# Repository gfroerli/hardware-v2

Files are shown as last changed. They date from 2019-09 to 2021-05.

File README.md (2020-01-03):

# Gfrörli Sensor Hardware v2

Based on the STM32L071KB microcontroller and the RN2483 LoRaWAN
modem.

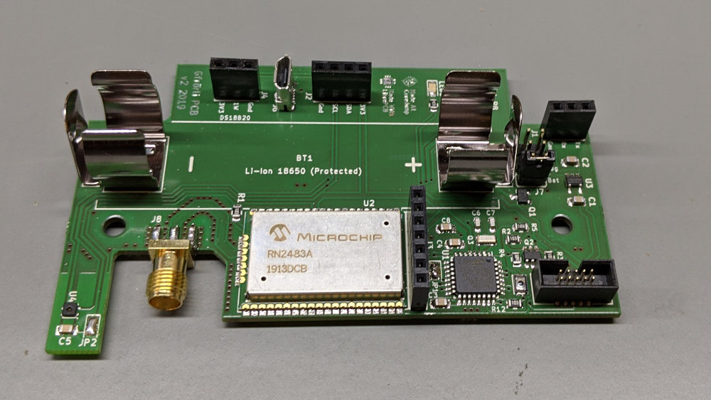
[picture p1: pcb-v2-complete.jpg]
Photo of assembled PCB


Aisler order link for v2.0: https://aisler.net/p/OROZOWMP

This is a [LibrePCB](https://librepcb.org) project!

## Docs

See [`docs/index.md`](./docs/index.md)

## License

No license set.

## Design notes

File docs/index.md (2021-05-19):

# Gfrör.li Documentation

## RN2483

See [`rn2483.md`](./rn2483.md).

## STM32L071

See [`stm32l071.md`](./stm32l071.md)

## Antenna / RF

See [`rf.md`](./rf.md)

## Debugger

We use the Segger JLink debugger.

The adaper used is the
[ARM-JTAG-20-10](https://www.digikey.ch/product-detail/de/olimex-ltd/ARM-JTAG-20-10/1188-1016-ND/3471401)
by OLIMEX.

- [Digikey](https://www.digikey.ch/product-detail/de/olimex-ltd/ARM-JTAG-20-10/1188-1016-ND/3471401)
- [Olimex Store](https://www.olimex.com/Products/ARM/JTAG/ARM-JTAG-20-10/)
- [Schematics](../datasheets/ARM-JTAG-20-10_latest-schematic.pdf)

## Powering the PCB

There are 3 ways to power the PCB:

- Battery power (3.3-4.2V)
- USB (5V)
- Debug probe (5V)

To choose the power source, the jumper J7 needs to be set appropriately.

If you want to power the board through the JLink debug probe, the solder bridge
R1 on the OLIMEX adapter must be closed. Then 5V power will be [supplied on pin
7 of the connector](../datasheets/ARM-JTAG-20-10_latest-schematic.pdf).

### Power Consumption

The peak power consumption is:
 * RN2483: ~40mA
 * STM32L071: ~10mA (IDD is 7.4mA according to datasheet Table 29.)
 * LEDs: ~10mA
 * SHTC3: ~1mA
 * DS18B20: ~1.5mA

So if we calculate with a peak power consumption of 100mA we should be on the safe side.

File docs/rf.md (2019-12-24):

# Antenna / RF

## Trace Calculations

The specs used by Aisler for their standard HASL boards:

- [FR-4-86](https://aisler.net/help/design-rules-and-specifications/specifications/2_layer_datasheet.pdf)
  - Dielectric constant / permittivity @ 1 MHz: Max 5.4 Measured 4.7
  - Loss Tangent @ 1 MHz: Max 0.035 Measured 0.02
- Copper thickness: 35 µm
- Board thickness: 1.6 mm

The current PCB layout uses a coplanar wave guide with ground plane.

With 0.3mm plane clearance:

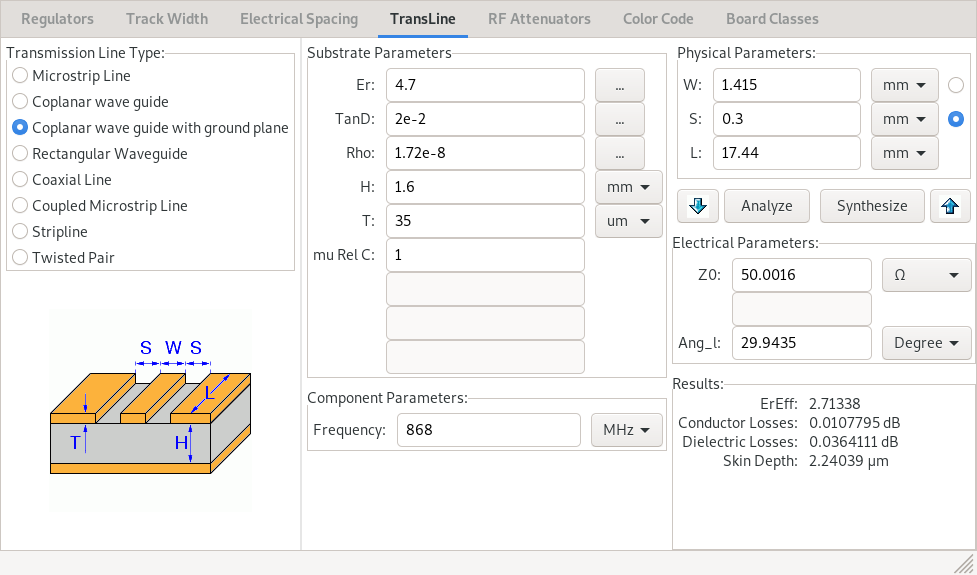
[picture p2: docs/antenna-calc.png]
Antenna coplanar waveguide calculations in KiCAD


With a trace width of 1.415 mm we should get an impedance of 50.0016 Ω.

See https://github.com/gfroerli/hardware-v2/issues/30 for more details.

## SMA Connector

We use a 50 Ω edge mount female SMA connector
[CON-SMA-EDGE-S](https://www.digikey.ch/products/en?keywords=%20CON-SMA-EDGE-S)
by RF Solutions. It seems to have the same footprint as the [Samtec
SMA-J-P-H-ST-EM1](https://www.digikey.com/product-detail/en/samtec-inc/SMA-J-P-H-ST-EM1/SAM8857-ND/2602450).

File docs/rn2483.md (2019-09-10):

# RN2483

## Information

 * https://www.microchip.com/wwwproducts/en/RN2483

## Firmware Update

See chapter 3.6 in the datasheet.

### Regular

The regular firmware upgrade happens through the bootloader via UART.

### Emergency

For the emergency firmware download (device bricked) one needs to connect
PGC\_INT, PGD\_INT NRESET, power and ground.

The NRESET pin will be driven with 9V during the upgrade, so any connected
parts may need protection!

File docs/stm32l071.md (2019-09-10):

# STM32L071

## Clock

See "Low-speed external clock generated from a crystal/ceramic resonator" in
the datasheet.

Our model only has the low-speed external clock pins. So we either use a more
precise external low speed clock or the less precise internal clocks.

## Nucleo Board (NUCLEO-L031K6)

The board we used for evaluation.

[Datasheet](../datasheets/STM32-Nucleo-32-boards.pdf)

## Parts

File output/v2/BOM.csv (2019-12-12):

Quantity | Designators | Value | Device | Package | PARTNUMBER | DIGIKEY | MANUFACTURER
1 | BT1 | 54 | Keystone 54 Battery Clips | KEYSTONE_54 | 54 | 36-54-ND | Keystone
2 | C1, C2 | 1μF | C-0805 | C-0805 | CL21B105KOFNNNG | 1276-6471-1-ND | Samsung
4 | C3, C4, C5, C8 | 100nF | C-0805 | C-0805 | CL21B104KACNNNC | 1276-1099-1-ND | Samsung
2 | C6, C7 | 4.3pF | C-0603 | C-0603 | CC0603CRNPO9BN4R3 | 311-3858-1-ND | Yageo
1 | J1 | UART1_DBG | Generic Pin Socket 2.54mm 1x03 ⌀1.0mm | Pin Socket 2.54mm 1x03 ⌀1.0mm | PPTC031LFBN-RC | S7001-ND | Sullins
1 | J2 | I2C | Generic Pin Socket 2.54mm 1x04 ⌀1.0mm | Pin Socket 2.54mm 1x04 ⌀1.0mm | PPTC041LFBN-RC | S7002-ND | Sullins
1 | J3 | RN | Generic Pin Socket 2.54mm 1x07 ⌀1.0mm | Pin Socket 2.54mm 1x07 ⌀1.0mm | PPTC071LFBN-RC | S7005-ND | Sullins
1 | J4 | DS18B20 | Soldered Wire Connector 2.54mm 1x03 ⌀1.0mm | Soldered Wire Connector 1x03 ⌀1.0mm | DFR0198 | DFR0198 | DFRobot
1 | J5 | SWD Connector 3220-10-0300-00 | CNC Tech 3220-10-0300 | CNCTECH_3220-10-0300-XX | 3220-10-0300-00 | 1175-1629-ND | CNC Tech
1 | J6 | Micro USB (power only) | Molex 1051330001 | MOLEX_1051330001 | 1051330001 | WM9734CT-ND | Molex
1 | J7 | Power Selector Jumper | Generic Pin Header 2.54mm 2x03 ⌀1.0mm | Pin Header 2.54mm 2x03 ⌀1.0mm | PRPC003DAAN-RC | S2011EC-03-ND | Sullins
1 | J7+ | Power Selector Jumper |  |  | QPC02SXGN-RC | S9337-ND | Sullins
1 | J8 | SMA CON-SMA-EDGE-S | RF Solutions CON-SMA-EDGE-S | RFSOL_CON-SMA-EDGE-S | CON-SMA-EDGE-S | CON-SMA-EDGE-S-ND | RF Solutions
1 | LED1 | R 2V 2.8mA | OSRAM LS R976-NR-1 | OSRAM CHIPLED 0805 Diffused | LS R976-NR-1 | 475-1278-1-ND | Osram
1 | LED2 | Y 2V 2.8mA | OSRAM LY R976-PS-36 | OSRAM CHIPLED 0805 Diffused | LY R976-PS-36 | 475-2560-1-ND | Osram
1 | LED3 | G 2.2V 2.3mA | OSRAM LG R971-KN-1 | OSRAM CHIPLED 0805 Diffused | LG R971-KN-1 | 475-1410-1-ND | Osram
1 | Q1 | SSM3J338R,LF | Toshiba SSM3J338R | SOT23-3 | SSM3J338R,LF | SSM3J338RLFCT-ND | Toshiba
1 | Q2 | DMG6601LVT | DMG6601LVT | SOT95P280X145-6 | DMG6601LVT | DMG6601LVT-7DICT-ND | Diodes Incorporated
1 | Q3 | 32,768Hz | NX3215SA Crystal | NDK_NX3215SA | NX3215SA-32.768KHZ-EXS00A-MU00529 | 644-1388-1-ND | NDK
6 | R1, R2, R3, R6, R7, R12 | 10kΩ | Resistor 2012 (0805) | RESC2012 (0805) | RC0805JR-0710KL | 311-10KARCT-ND | Yageo
1 | R4 | 6.04kΩ 0.1% | Resistor 2012 (0805) | RESC2012 (0805) | RC0805FR-076K04L | 311-6.04KCRCT-ND | Yageo
1 | R5 | 9.31kΩ 0.1% | Resistor 2012 (0805) | RESC2012 (0805) | RC0805FR-079K31L | 311-9.31KCRCT-ND | Yageo
3 | R8, R9, R10 | 470Ω | Resistor 2012 (0805) | RESC2012 (0805) | RC0805JR-07470RL | 311-470ARCT-ND | Yageo
1 | R11 | 4.7kΩ | Resistor 2012 (0805) | RESC2012 (0805) | RC0805JR-074K7L | 311-4.7KARCT-ND | Yageo
1 | S1 | KXT 321 LHS | KXT3x1LHS | CK_KXT3x1LHS | KXT 321 LHS | CKN10778CT-ND | C&K
1 | U1 | STM32L071KBT6 | STM32L071KxTx | LQFP80P900X900X140-32 | STM32L071KBT6 | 497-18577-ND | ST Microelectronics
1 | U2 | RN2483A-I/RM105 | RN2483 | RN2483 | RN2483A-I/RM105 | RN2483A-I/RM105-ND | Microchip
1 | U3 | LP5907QMFX-3.3Q1 | LP5907-Q1 | SOT95P280X145-5 | LP5907QMFX-3.3Q1 | 296-40365-1-ND | Texas Instruments
1 | U4 | SHTC3 | SHTC3 | Sensirion SHTCx | SHTC3 | 1649-1100-1-ND | Sensirion

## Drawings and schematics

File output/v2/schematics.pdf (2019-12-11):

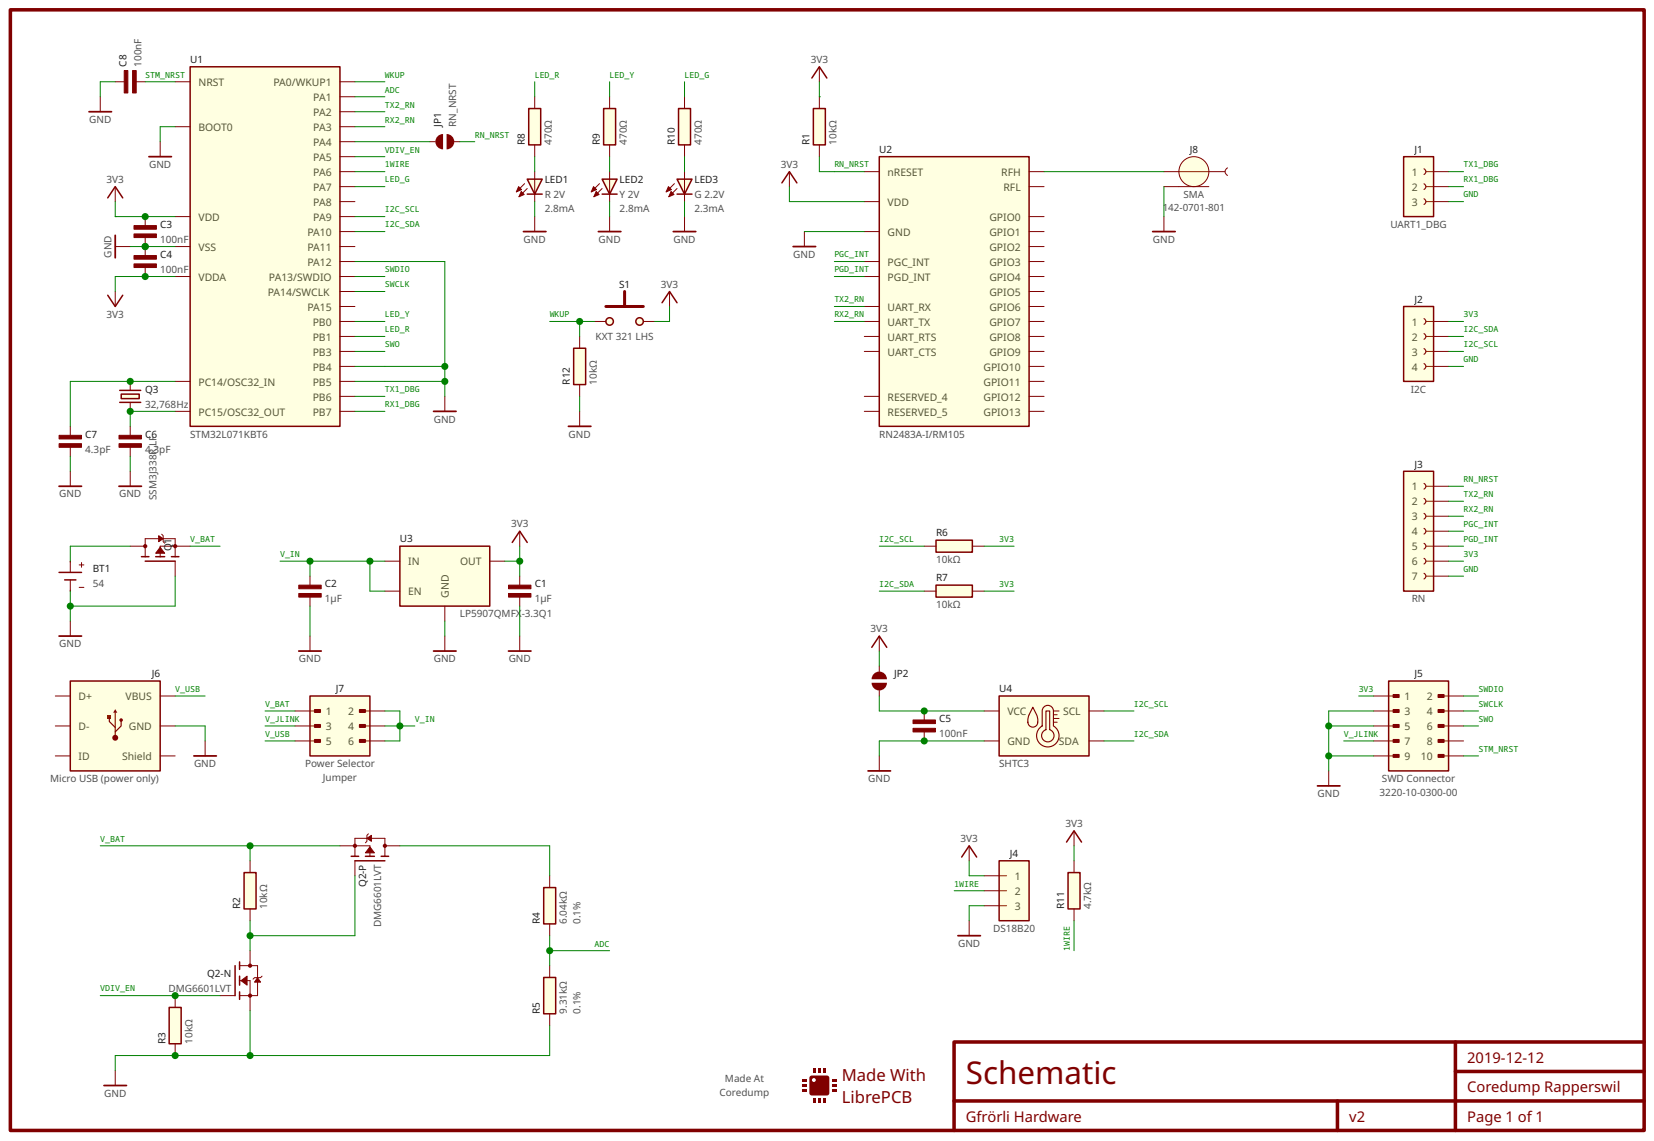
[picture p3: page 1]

Micro USB (power only)

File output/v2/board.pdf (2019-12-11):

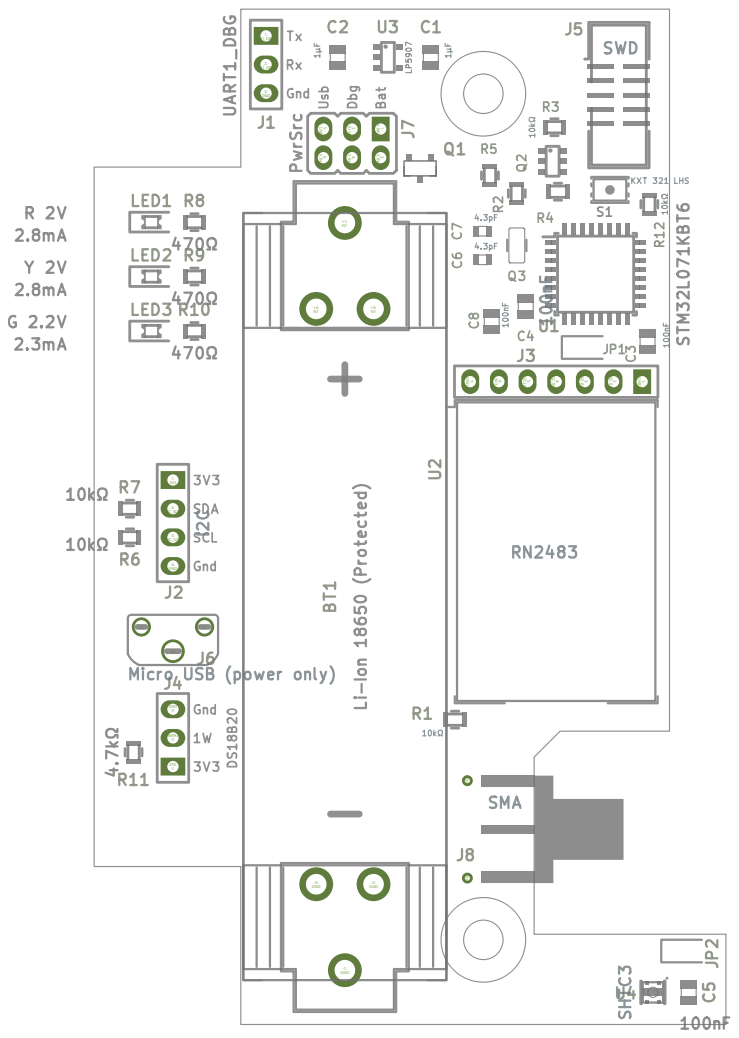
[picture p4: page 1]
PTH2: PTH1:; 4: PGC_INT; 7: GND; 1: RN_NRST; 5: PGD_INT; 3: I2C_SCL; 2: I2C_SDA; 4: GND; -2: GND; -1: GND; -3: GND; 5: V_USB; 1: V_BAT; 3: GND; 1: TX1_DBG; 2: RX1_DBG

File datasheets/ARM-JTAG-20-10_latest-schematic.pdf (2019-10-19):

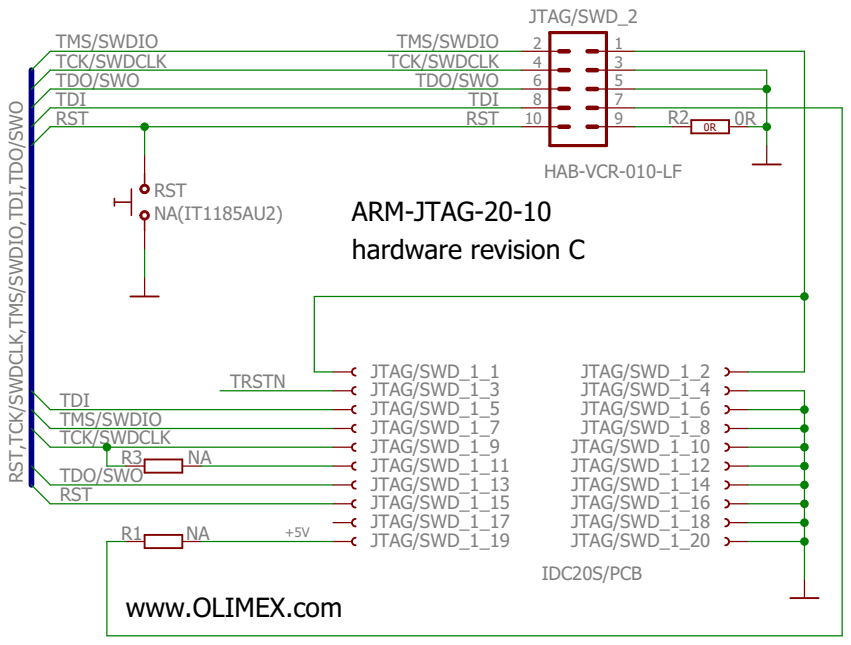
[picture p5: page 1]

RST,TCK/SWDCLK,TMS/SWDIO,TDI,TDO/SW

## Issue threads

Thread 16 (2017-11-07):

Think about DS18B20 pull up resistor value

rnestler, 2017-11-07:
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
Do we need such a low resistance pull-up? (power consumtion...)

But this is a minor issue, since it doesn't influence the PCB. We can change it later.

dbrgn, 2019-06-15:
https://www.maximintegrated.com/en/support/faqs/ds18b20-faq.html

>  Is the 4.7kΩ resistor needed for 5V and 3.3V operation?
> Yes, the 4.7kΩ pullup resistor is required for both 5V and 3.3V applications.

Closed 2019-08-06.

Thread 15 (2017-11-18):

Connector for Power

rnestler, 2017-11-18:
In a lab environment it's more practical to use a bench-top power supply than a battery.

dbrgn, 2019-10-17:
We decided to go with a Micro-USB connector for now.

@rnestler do we need protection against having both the battery and USB connected, or do we assume everybody that connects power to the USB connector knows what they're doing?

Might battery power (3-4V) going *into* the USB connector damage the computer as well?

rnestler, 2019-11-03:
> Might battery power (3-4V) going into the USB connector damage the computer as well?

We discussed this right? The conclusion was using the jumper as protection right?

dbrgn, 2019-11-03:
Yep!

Closed 2019-10-19.

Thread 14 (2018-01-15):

Larger NPTH (screw holes)

dbrgn, 2018-01-15:
The holes for the screws are quite tight.

Also, distance from parts is not too large.

dbrgn, 2019-12-02:
Diameter of screw head is 7.15 mm.

dbrgn, 2019-12-02:
Unfortunately keepout zones aren't yet possible under the screws (https://github.com/LibrePCB/LibrePCB/issues/598)

Closed 2019-12-02.

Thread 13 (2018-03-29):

Connect RN2483 RST to uC

dbrgn, 2018-03-29:
Make it possible to reset RN2483 from microcontroller.

dbrgn, 2019-10-19:
Connected the RN NRST pin to PA4 of the uC in a106bb9cf53bd7193c020e8b031854147a7ee80d.

TODO:

- @rnestler can you confirm that this should work? (See commit message)
- We should test this using the nucleo devboard.

rnestler, 2019-12-07:
From the commit message:
> By default, after reset, the GPIO pins of the uC are configured as
floating inputs (see datasheet table 14). If we enable the pull-down
resistor on PA4, we should be able to reset the RN module.

Uhm what? If you have a pull up and a pull-down it will be a voltage in between the logic levels which may not work or even break stuff.
Why not do the obvious thing and configure it as an open drain output and set it to 0 to reset?

rnestler, 2019-12-07:
> We should test this using the nucleo devboard.

That's probably a smart thing to do anyways :)

dbrgn, 2019-12-07:
>  Why not do the obvious thing and configure it as an open drain output and set it to 0 to reset?

Uhh, that's what I meant to write :sweat_smile:

dbrgn, 2019-12-10:
We don't have the Nucleo board at hand, so we'll trust that it works :slightly_smiling_face:

Closed 2019-12-10.

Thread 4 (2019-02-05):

Allow powering through JLINK

dbrgn, 2019-02-05:

dbrgn, 2019-10-19:
The Olimex SWD-Adapter requires adding a solder bridge on R1, then 5V supply will be provided through pin 7 of the connector.

(Schematics: https://github.com/gfroerli/hardware-v2/blob/master/datasheets/ARM-JTAG-20-10_latest-schematic.pdf)

Closed 2019-10-19.

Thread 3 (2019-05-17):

Connect BOOT0 pin

dbrgn, 2019-05-17:
On the STM32L0, make sure to connect the BOOT0 pin so it doesn't float.

From the [reference manual](https://www.st.com/content/ccc/resource/technical/document/reference_manual/21/bd/0f/bd/1c/88/40/f0/DM00108282.pdf/files/DM00108282.pdf/jcr:content/translations/en.D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):

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

From IRC:

```
14:24 < therealprof1> dbrgn: Yeah, there's some weird quirks and error modes for some
                      of the chips. Is this a Nucleo board or some custom hardware?
14:25 < therealprof1> In case the latter, I'd recommend checking out the BOOT pin(s),
                      if they're floating in the breeze you'll experience fancy
                      random errors every now and then.
```

Closed 2019-06-14.

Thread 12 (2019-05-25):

Allow disconnecting RN from rest of the board

dbrgn, 2019-05-25:
This would allow flashing it without affecting the uC.

rnestler, 2019-09-10:
So there are two issues right?:
 * Short circuits  / conflicts on the UART pins
 * The 9V on the NRST pin when using the ICP

dbrgn, 2019-10-19:
> Short circuits / conflicts on the UART pins

Are there UART conflicts?

> The 9V on the NRST pin when using the ICP

Yep, that's the main issue.

rnestler, 2019-10-30:
> Are there UART conflicts?

Well yes: The PC sends stuff to update the FW and the uC sends stuff to send measurements over LoRa.

dbrgn, 2019-10-30:
Yeah, but during FW upgrade the uC should not be running at all, so that shouldn't be an issue.

rnestler, 2019-11-03:
> Yeah, but during FW upgrade the uC should not be running at all, so that shouldn't be an issue.

But then we need to take care to not powering the uC through the UART pins, which could lead to strange effects.

dbrgn, 2019-11-03:
Ok, good point. I wasn't aware that this could happen :)

rnestler, 2019-12-07:
> > The 9V on the NRST pin when using the ICP
>
> Yep, that's the main issue.

After thinking about it, the 10k resistor already protects the 3.3V rails from the 9V, but PA4 of the micro controller is also connected to it. So we'd need to protect that pin.

rnestler, 2019-12-07:
> Yeah, but during FW upgrade the uC should not be running at all, so that shouldn't be an issue.

We could pull the reset pin of the uC to low during FW upgrade of the RN module.

dbrgn, 2019-12-07:
That could work. It's not currently accessible through a header though, right?

dbrgn, 2019-12-10:
Power can be disconnected using the JP1 jumper.

If we need to reset the uC by pulling down STM_NRST, we can add a connection across C8.

Closed 2019-12-10.

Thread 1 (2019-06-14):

Evaluate alternatives for oscillator

dbrgn, 2019-06-14:
Can/should we use a different one than on the previous board?

rnestler, 2019-06-15:
We should probably use the one recommended by the uC datasheet :wink:

dbrgn, 2019-11-29:
I did some more research in how to pick an oscillator and how to choose the capacitance.

I found these two links:

- [ST AN2867](https://www.st.com/content/ccc/resource/technical/document/application_note/c6/eb/5e/11/e3/69/43/eb/CD00221665.pdf/files/CD00221665.pdf/jcr:content/translations/en.C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)
- https://blog.adafruit.com/2012/01/24/choosing-the-right-crystal-and-caps-for-your-design/

The oscillator we picked ([NX3215SA-32.768KHZ-EXS00A-MU00525](https://www.digikey.com/products/en?keywords=644-1386-1-ND)) has a load capacitance of 6 pF. Using the formula `(C*C) / (C+C) + Cs = 6` and a `C` value of 4.3 pF (the value we picked in the schematics right now), we end up with a stray capacitance of 3.85 pF to reach the target `6 pF`. However, the [datasheet](https://github.com/gfroerli/hardware-v2/blob/master/datasheets/stm32l071xxx.pdf) says that `10 pF` can be used as a rough estimate of Cs:

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

This text was about the HSE (high-speed) while the 32 kHz oscillator we use is a LSE. Does that guide still apply? Is this something we should test experimentally once we have a PCB?

rnestler, 2019-12-03:
Well we used the same values as the nucleo board, so I think we are fine.

dbrgn, 2019-12-07:
This can be closed, right?

Closed 2019-12-07.

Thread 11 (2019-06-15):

Add solder bridges to disconnect parts of the circuit from power

rnestler, 2019-06-15:
This allows to measure power usage of components separately.

dbrgn, 2019-10-19:
Since we don't have a solder bridge / 0 ohm resistor device yet, create it in the gfrörli library (and create a PR against the official library).

dbrgn, 2019-12-02:
We can simply use a standard resistor with a value of 0 Ω.

dbrgn, 2019-12-06:
Solder jumper sym/cmp added here: https://github.com/LibrePCB-Libraries/LibrePCB_Base.lplib/pull/52

rnestler, 2019-12-07:
For the solder bridges one would want something like 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 for the footprint.

rnestler, 2019-12-10:
We decided against doing this for everything, due to space constraints. So just for the SHTC3.

Closed 2019-12-16.

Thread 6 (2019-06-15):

Add SMA connector

rnestler, 2019-06-15:
Keep the following in mind:
 * The SMA connector pads shouldn't be in the stencil mask, since we can't really re-flow solder it.
 * Keep in mind to have soldermask opening in top and the bottom layers.

dbrgn, 2019-08-06:
Blocked by https://github.com/LibrePCB-Libraries/Cinch_Connectivity_Solutions.lplib/pull/1

Closed 2019-10-19.

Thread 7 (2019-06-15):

Check uC NRST Pin

rnestler, 2019-06-15:
Should we pull it up to VDD?

rnestler, 2019-09-10:
According to the datasheet and reference design a 100nF capacitor to GND should be added.

Closed 2019-09-10.

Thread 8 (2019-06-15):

Add button to WKUP1

rnestler, 2019-06-15:
It would be nice to wake up the device externally:
 * It enables us to trigger a measurement, which is nice for testing
 * If the device is in sleep sending commands / debugging via UART won't be possible.

dbrgn, 2019-12-03:
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

Closed 2019-12-03.

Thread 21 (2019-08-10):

Add buffering capacitor for sending messages?

dbrgn, 2019-08-10:

rnestler, 2019-08-19:
Doesn't the module already include some buffering capacitors? How much capacity would we need then to avoid voltage drops?

dbrgn, 2019-08-19:
I don't know, we'd have to measure it.

dbrgn, 2019-10-19:
@rnestler should we leave this away in the first version, or already provide a footprint for a cap?

rnestler, 2019-11-03:
> @rnestler should we leave this away in the first version, or already provide a footprint for a cap?

If there is space, provide a footprint, if not or it would be annoying to make space for it just leave it out for v1. In the worst case we need to solder a THT capacitor to the device.

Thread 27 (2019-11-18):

Verify suitability of LDO

dbrgn, 2019-11-18:
Are the 250 mA peak power of the LP5907 sufficient, or do we need a bit more headroom?

rnestler, 2019-12-02:
250mA should be enough for everyone!

The RN module draws ~40mA when transmitting, the uC probably takes no more than 5mA and the few other peripherals also shouldn't add up to more than a few millis.

Closed 2019-12-02.

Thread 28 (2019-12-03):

Check if we can measure the battery voltage below 3.3V

rnestler, 2019-12-03:
Currently it seems that we can only reliably measure the battery voltage down to 3.3V, because after that the ADC reference will also drop.

rnestler, 2019-12-03:
I guess we could use V<sub>REFINT</sub> for that.
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

dbrgn, 2019-12-07:
Hm, maybe I'm stupid, but I can't find the ADC_IN17 pin in the datasheet. (Other pins like ADC_IN10 or ADC_IN15 are listed in the pin definition table.

rnestler, 2019-12-07:
> ADC_IN17 pin

That's because it isn't a pin :wink: It is the *internal* bandgap which is connected internally to the `ADC_IN17` channel.

dbrgn, 2019-12-07:
Ah! So we wouldn't need to do any changes to the schematics to use this, right?

rnestler, 2019-12-10:
> Ah! So we wouldn't need to do any changes to the schematics to use this, right?

We'd probably need to change the voltage divider to keep the voltage between 0..V<sub>REFINT</sub>. But no change for the layout at least.

rnestler, 2020-08-04:
We could also consider using the V_LCD voltage monitoring:
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

dbrgn, 2021-07-20:
The internal ADC reference (V_REFINT):

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

Here are the specs:

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

dbrgn, 2021-07-20:
We need to adjust the voltage divider resistor values so that we can properly measure these values.

The exact reference value is stored in the `VREFINT_CAL` register. The max value is 1.242 V.

The resistor values must be chosen so that they map an input range of 0-5 V to the range 0-1.242V.

Existing divider:

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

We could use the following two values from the E24 1% series:

- R4: 9.1K
- R5: 3K

With this, we get:

- 1.242 V (MAX) for an input of 5.01 V
- 0.818 V for an input of 3.3 V
- 0.62 V for an input of 2.5 V

The ADC has 12 bit of accuracy. That means the ADC measures in steps of 0.3 mV (1.242 / 4096 * 1000). That should be plenty.

@rnestler does that look good? The ADC is saturating, so if we had a voltage of 5.1V we'd still get the max value (4096), right?

dbrgn, 2021-08-03:
(Right now, the measured voltage doesn't drop below 3.43 V.)

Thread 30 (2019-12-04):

Connect RN2483 with antenna

dbrgn, 2019-12-04:
I gave it a try.

[Specs used by Aisler](https://aisler.net/help/design-rules-and-specifications/specifications):

- [FR-4-86](https://aisler.net/help/design-rules-and-specifications/specifications/2_layer_datasheet.pdf)
  - Dielectric constant / permittivity @ 1 MHz: Max 5.4 Measured 4.7
  - Loss Tangent @ 1 MHz: Max 0.035 Measured 0.02
- Copper thickness: 35 µm

With 1.6mm board thickness and 0.3mm plane clearance:

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

With 2mm board thickness:

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

I assumed 1.6mm thickness and made an attempt at drawing the trace:

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

With the 1.415mm trace width we're at 50.0016 Ohms.

The length is roughly 17.44mm, this results in an angle(?) of 29.94°.

Does this look good? Are the input values correct? What does the angle mean?

dbrgn, 2019-12-04:
Interestingly, the [RN2483 datasheet](http://ww1.microchip.com/downloads/en/DeviceDoc/50002346C.pdf) suggests a different design:

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

dbrgn, 2019-12-04:
Note: The edge mount SMA connector is made for a board thickness of 1.57mm (space is 1.73mm).

rnestler, 2019-12-07:
> What does the angle mean?

Probably the resulting phase shift of the signal. Should increase proportional with the length of the trace.

rnestler, 2019-12-07:
In the old board we made it like this;
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
Since it worked quite well I guess we are fine as well.

Could you document all the decision making and sources for the PCB specs etc. in the `docs` folder?

dbrgn, 2019-12-07:
> Since it worked quite well I guess we are fine as well.

Ok! I'll also add a few more vias around the trace.

> Could you document all the decision making and sources for the PCB specs etc. in the docs folder?

Yep, can do that!

dbrgn, 2019-12-07:
> Probably the resulting phase shift of the signal. Should increase proportional with the length of the trace.

Yep, it does. Is it relevant for us?

rnestler, 2019-12-07:
> Plane clearance: 0.3mm

On https://aisler.net/help/design-rules-and-specifications/2-and-4-layer-design-rules it says that the min. spacing trace / ground plane is 0.2mm

dbrgn, 2019-12-07:
Ah, that part is not a spec by Aisler, it's the plane configuration we're using right now. I should have moved it to a different section, will fix.

dbrgn, 2019-12-09:
Ok, stitching vias added. Should be OK now.

dbrgn, 2019-12-13:
Note: Footprint replaced with [this one](https://www.digikey.ch/products/en?keywords=%20CON-SMA-EDGE-S) due to price (1.68 CHF instead of >10).

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

The connector seems to be basically the same as the [Samtec SMA-J-P-H-ST-EM1](https://www.digikey.com/product-detail/en/samtec-inc/SMA-J-P-H-ST-EM1/SAM8857-ND/2602450).

Closed 2019-12-09.

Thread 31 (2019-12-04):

SMA connector fixes

dbrgn, 2019-12-04:
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

Either remove those vias, or connect them to the GND net.

rnestler, 2019-12-10:
Is this really fixed? It still shows up as a DRC error for me :/

dbrgn, 2019-12-10:
> Is this really fixed? It still shows up as a DRC error for me :/

Hm, you mean these errors?

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

Strange, clearance between "GND" and ""... Looks like a bug to me.

The device looks like this:

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

So the two pads are connected to the same net as the GND legs.

Closed 2019-12-06.

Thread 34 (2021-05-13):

Replace LDO

dbrgn, 2021-05-13:
Right now we're using the [LP5907-Q1](https://www.ti.com/lit/ds/symlink/lp5907-q1.pdf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). I'm not sure what we were thinking when picking it (probably nothing), but it has an I_Q of at least 12 uA (in practice it seems to be around 15-16 uA).

These two models seem to be drop-in replacements:

- [TPS7A02 (25nA I_Q, 1.23 CHF @ Q10)](https://www.ti.com/lit/ds/symlink/tps7a02.pdf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)
- [TPS7A03 (200nA I_Q, 0.73 CHF @ Q10)](https://www.ti.com/lit/ds/symlink/tps7a03.pdf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)

They can deliver up to 200 mA (previous model offered 250 mA), but that should be sufficient.

To be determined:

- Will they work as drop-in replacements? (Pinout seems to be the same)
- Which one? (Price isn't really an issue, so I'd go with the 25nA TPS7A02 even if it's expensive.)

CC @rnestler

rnestler, 2021-05-19:
Well the dropout voltage seems higher (but difficult to compare, since they give it only for 200mA load).

dbrgn, 2021-05-19:
> since they give it only for 200mA load

From the datasheet:

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

dbrgn, 2021-05-19:
The one on the left is for 5V output voltage. We're using 3.3V, so it should be lower. Here's 1.8V:

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

rnestler, 2021-05-19:
Ah, I did only check the tables. The old one had:
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

rnestler, 2021-05-19:
> We're using 3.3V, so it should be lower. Here's 1.8V

Well if you look at the graph, at 50mA (which we need during TX) the dropout is around 100mA@1.8V while it is 80mA@5V. So I don't agree that it is lower.

dbrgn, 2021-05-19:
Ah, you're right, I missed that.

The main issue here is that the uC might brown-out due to the high dropout voltage when we have current spikes due to LoRaWAN transmissions, right?

rnestler, 2021-05-19:
> The main issue here is that the uC might brown-out due to the high dropout voltage when we have current spikes due to LoRaWAN transmissions, right?

Yes. But also less run time if the battery voltage goes down.

dbrgn, 2021-05-19:
Sure, but during sleep the power consumption is really low, so we're mostly bound by the peak current, right?

So, it seems to be an optimization problem bound by LDO quiescent current, LDO drop-out voltage, avg current during sleep, avg current during measurement, peak current during transmission and duration of the measurement phase.

Are there tools to calculate this optimization problem? I assume it should be pretty common?

rnestler, 2021-05-19:
IMO the quiescent current is more important for us, since our battery won't go below 3.3V until it is almost empty anyways, right?

dbrgn, 2021-05-19:
We'd need to profile that, but yes, I'd estimate that when it goes below 3.3V, less than 10% of the capacity are left.

See this chart, taken from [here](https://lygte-info.dk/review/batteries2012/Samsung%20INR18650-35E%203500mAh%20%28Pink%29%20UK.html):

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

(This is one of the batteries we're using.)

dbrgn, 2021-05-29:
For the record, we [compared different models](https://md.coredump.ch/gfroerli-ldo) and found two candidates:

- [Ablic S-1317A33-M5T1U4](https://www.digikey.ch/product-detail/de/ablic-u-s-a-inc/S-1317A33-M5T1U4/1662-2848-1-ND/7927985)
- [TI TPS782](https://www.digikey.ch/product-detail/de/texas-instruments/TPS78233DDCR/296-24059-1-ND/1990152)

We wanted to test and compare both, but unfortunately the TPS782 is not in stock on Digikey. Therefore we'll first try the Ablic LDO. It's pin-compatible with the current LDO.

Note: The TPS872 requires pin 4 to be connected to GND, while right now it's floating. On the prototype we can solder in a jumper wire, but we should fix this on the next revision: https://github.com/gfroerli/hardware-v2/issues/36

dbrgn, 2021-07-20:
The Ablic LDO works great!

Fixed in https://github.com/gfroerli/hardware-v2/commit/858049d78f3449aeb47347d26a1fda94862666c2.

Closed 2021-07-20.

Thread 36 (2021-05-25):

LDO: Connect pin 4 to GND

dbrgn, 2021-05-25:
While our current LDO has pin 4 marked as N/C, some LDOs (like the TI TPS782) want it connected to GND.

Connect it to GND for more flexibility in LDO choice.

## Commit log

2019-05-25 Add I2C header
2019-06-14 Add battery and LDO
2019-06-14 Connect uC to power supply
2019-06-14 Add battery voltage measurement circuit
2019-06-14 Add SHTC3 and I2C Pullups
2019-06-14 Pull BOOT0 pin to GND (#3)
2019-06-15 Add 1 wire connector (#5)
2019-07-12 Add LEDs
    Red, Yellow, Green.
2019-08-06 LEDs: Limit current to 10 mA
2019-08-06 Add pull-up resistor for DS18B20 (#19)
    4.7 kΩ, as suggested by the datasheet.
    Fixes #16
2019-08-06 Add hardware version detection (#20)
    Reserve 3 GPIO pins for version detection (PB3-5), pulled down to GND (v=0).
2019-08-24 Remove RN UART header (fixes #17)
2019-09-10 Use the oscillator design from the Nucleo board (#23)
    Fixes #1
2019-09-10 Add STM32L071 documentation
2019-09-10 Add Nucleo board datasheet and docs
2019-10-19 Add Diode datasheet link
2019-10-19 Add USB connector to schematics
2019-10-19 Rename connectors, make designators more logical
2019-10-19 Add SWD debug connector
2019-10-19 Add jumper to protect protect battery from USB
    Unless someone adds a 3-position jumper, this will protect the device
    from having both USB and battery power at the same time.
2019-10-19 SWD Connector: Connect SWO pin
2019-10-19 Docs: Fix Datasheet -> Schematics
2019-10-19 Allow powering the board through the JLink debugger
    Fixes #4
2019-10-19 Add SMA connector
    Fixes #6
2019-10-19 Connect RN reset pin to PA4
    The NRST pin is pulled up using the pull-up resistor R1. It's also
    connected to the PA4 pin of the microcontroller.
    By default, after reset, the GPIO pins of the uC are configured as
    floating inputs (see datasheet table 14). If we enable the pull-down
    resistor on PA4, we should be able to reset the RN module.
    Refs #13
2019-10-19 Start with PCB layout
2019-10-19 Continue routing board
2019-10-19 Board: Add LEDs
2019-10-25 Split up groundplanes
2019-11-29 Add logos to PCB
2019-11-30 More space around mounting holes (#14)
2019-12-02 Place USB connector and R1 resistor (#13)
2019-12-02 Ensure clearance around screws (#14)
2019-12-02 Improve clearance around screw on the bot layer (#14)
2019-12-03 Add button and some stitching vias (#8)
2019-12-03 Select oscillator capacitors (#1)
    Select 4.3pF capacitors from Digikey and switch to 0603.
2019-12-03 Add missing devices
2019-12-04 Draw antenna connection for RN2483 (#30)
2019-12-04 SMA Connector: Add PARTNUMBER and DIGIKEY attributes
2019-12-06 Update SMA connector (#31)
2019-12-09 Add more stitching vias around antenna trace (#30)
2019-12-09 Add solder bridge between uC and RN_RST
2019-12-10 Fix bad trace
2019-12-11 Use 470Ohm resistor for all LEDs
    Previously the LEDs could draw up to 10mA which is a bit much. Also
    there isn't much value in using different resistors for the LEDs. 470Ohm
    is also the value we used before.
2019-12-11 Pick devices for C3/C4
2019-12-11 Board: Enable stencil layer
2019-12-11 Improve placement layer
    - Move labels
    - Add labels for DS18B20 pins
    - Add labels for I2C pins
2019-12-11 Add solder bridge to disconnect SHTC3 from power
    See #11
2019-12-11 Finish BOM
2019-12-11 Fix connection in board
2019-12-11 Generate fabrication data for v2.0
    [Gfrorli_Hardware_COPPER-BOTTOM.gbr, Gfrorli_Hardware_COPPER-TOP.gbr, Gfrorli_Hardware_DRILLS-NPTH.drl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]
2019-12-11 Add v2.0 BOM
    [BOM.csv]
2019-12-11 Fix groundplane
2019-12-11 Re-generate fabrication data for v2.0
    [Gfrorli_Hardware_COPPER-BOTTOM.gbr, Gfrorli_Hardware_COPPER-TOP.gbr, Gfrorli_Hardware_DRILLS-NPTH.drl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]
2019-12-12 Add J7 jumper to BOM
    [BOM.csv]
2019-12-12 Reformat BOM
    - Use commas as separator
    - Remove entries that don't correspond to a device (e.g. logos)
    [BOM.csv]
2019-12-12 Replace SMA connector
    The Cinch connector is too expensive, use one by RF Solutions instead.
    [BOM.csv]
2019-12-24 docs: Add section about power supply
2019-12-24 docs: Document antenna / trace design choices
    Refs #30
2019-12-24 datasheets: Add STM32L0x1 reference manual
2020-01-03 Add photo of PCB
2020-06-28 Fix ugly trace routing below STM32L0
2021-05-19 Document power consumption (#35)
